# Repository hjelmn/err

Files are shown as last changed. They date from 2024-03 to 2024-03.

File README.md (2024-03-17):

This project contains all the files from my recreation of the Err LED sign. Included
in this repository are the current Kicad files.

The board is roughly based on the data available at:

https://hackaday.io/project/183827-reverse-engineering-the-mooninite-led-panels/details

with minor modifications (there could be errors-- if you find some please post a
PR with the fix):

 - Added a tactile switch to control the mode of the panel. The modes are off,
   light triggered, and various dimmed states but this can be changed by
   modifying the PIC firmware.
 - Added a barrel power input to support an external power supply. Added a
   circuit to disable the batter if an external power supply is connected. This
   circuit uses a P-channel MOSFET which closes the Batt+ when a voltage is
   detected on Vcc.
 - Added a battery pack connector and pads to solder on a battery.
 - Increased the LED driver voltage from 12v to 24v using boost regulator.
 - Changed the 5v regulator to a D2Pak style from the TO-220.
 - Added a 24 channel dimmable LED driver and rewired LEDs in chains of 6-8.
 - Changed to PIC16 to get I2C support but that is not needed with the LED
   controller chosen. It uses PWR so the originsl PIC12 is likely sufficient.

TODO:

 - Code for the microcontroller. Waiting on getting the parts before the code is
   finished.

The current version of the board costs roughly $85 to produce with LEDs from
China and parts sourced from the US.

To use this project download kicad and open the project.

The license for all of these files is GPLv3.

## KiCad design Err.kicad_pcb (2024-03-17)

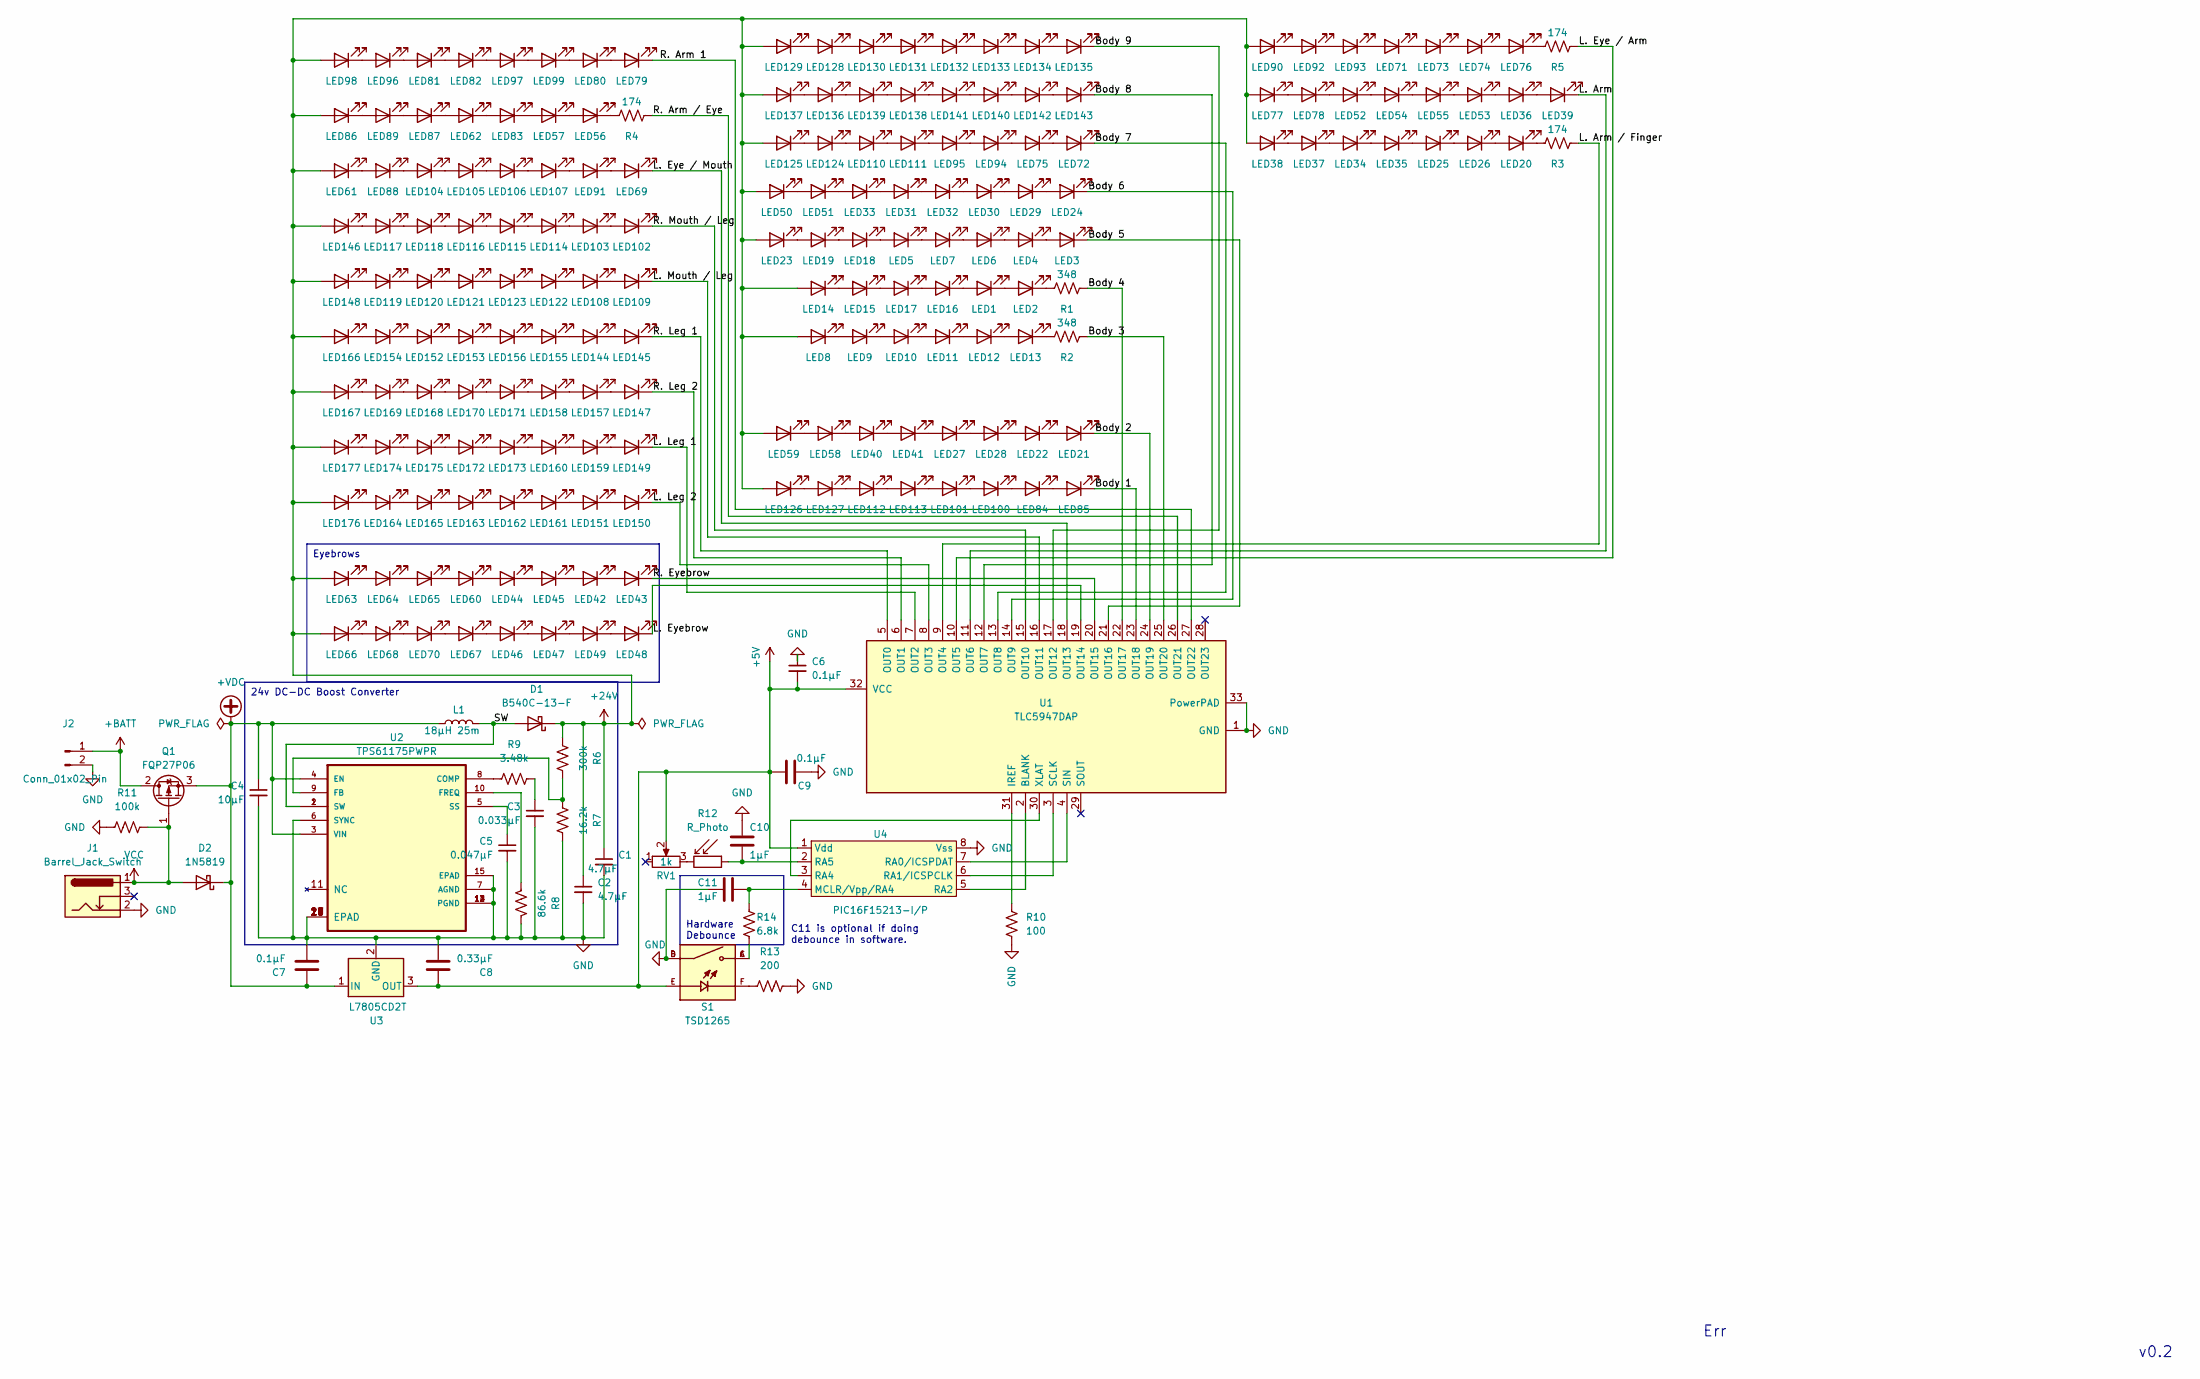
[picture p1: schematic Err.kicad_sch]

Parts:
C1, C2: 4.7µF; C_1206_3216Metric_Pad1.33x1.80mm_HandSolder; Part GRM31CR71H475KA12L
C3: 0.033µF; C_0805_2012Metric_Pad1.18x1.45mm_HandSolder; Part CGA4J2C0G1H333J125AA
C4: 10µF; C_1206_3216Metric_Pad1.33x1.80mm_HandSolder; Part GRM31CR71E106KA12L
C5: 0.047µF; C_0805_2012Metric_Pad1.18x1.45mm_HandSolder; Part C0805C473J3GACTU
C6: 0.1µF; C_0805_2012Metric_Pad1.18x1.45mm_HandSolder; Part GRM31CR71H475KA12L
C7, C9: 0.1µF; C_Disc_D3.0mm_W2.0mm_P2.50mm; Part C320C104K5R5TA
C8: 0.33µF; C_Disc_D5.1mm_W3.2mm_P5.00mm; Part SR215E334MAATR1
C10, C11: 1µF; C_Disc_D5.1mm_W3.2mm_P5.00mm; Part C330C105K5R5TA7301
D1: B540C-13-F; D_SMC-RM10_Universal_Handsoldering; Part B540C-13-F
D2: 1N5819; D_DO-41_SOD81_P10.16mm_Horizontal; Part 1N5819
J1: Barrel_Jack_Switch; BarrelJack_Wuerth_6941xx301002; Part SparkFun PRT-00119
J2: Conn_01x02_Pin; JST_EH_B2B-EH-A_1x02_P2.50mm_Vertical; Part B2B-XH-A
L1: 18µH 25m; IND_SRR1208-120ML; Part SRR1208-180ML
LED1, LED2, LED3, LED4, LED5, LED6, LED7, LED8, LED9, LED10, LED11, LED12, LED13, LED14, LED15, LED16, LED17, LED18, LED19, LED21, LED22, LED23, LED24, LED27, LED28, LED29, LED30, LED31, LED32, LED33, LED40, LED41, LED50, LED51, LED58, LED59, LED72, LED75, LED84, LED85, LED94, LED95, LED100, LED101, LED110, LED111, LED112, LED113, LED124, LED125, LED126, LED127, LED128, LED129, LED130, LED131, LED132, LED133, LED134, LED135, LED136, LED137, LED138, LED139, LED140, LED141, LED142, LED143: LED; LED_D10.0mm; Part 10mm Pink LED
LED20, LED25, LED26, LED34, LED35, LED36, LED37, LED38, LED39, LED42, LED43, LED44, LED45, LED46, LED47, LED48, LED49, LED52, LED53, LED54, LED55, LED56, LED57, LED60, LED61, LED62, LED63, LED64, LED65, LED66, LED67, LED68, LED69, LED70, LED71, LED73, LED74, LED76, LED77, LED78, LED79, LED80, LED81, LED82, LED83, LED86, LED87, LED88, LED89, LED90, LED91, LED92, LED93, LED96, LED97, LED98, LED99, LED102, LED103, LED104, LED105, LED106, LED107, LED108, LED109, LED114, LED115, LED116, LED117, LED118, LED119, LED120, LED121, LED122, LED123, LED144, LED145, LED146, LED147, LED148, LED149, LED150, LED151, LED152, LED153, LED154, LED155, LED156, LED157, LED158, LED159, LED160, LED161, LED162, LED163, LED164, LED165, LED166, LED167, LED168, LED169, LED170, LED171, LED172, LED173, LED174, LED175, LED176, LED177: LED; LED_D10.0mm; Part 10mm Blue LED
Q1: FQP27P06; TO-220-3_Horizontal_TabDown; Part FQP27P06
R1, R2: 348; R_Axial_DIN0207_L6.3mm_D2.5mm_P10.16mm_Horizontal; Part MFR-25FBF52-348R
R3, R4, R5: 174; R_Axial_DIN0207_L6.3mm_D2.5mm_P10.16mm_Horizontal; Part MFR-25FRF52-174R
R6: 300k; R_0603_1608Metric_Pad0.98x0.95mm_HandSolder; Part RC0603FR-07300KL
R7: 16.2k; R_0402_1005Metric_Pad0.72x0.64mm_HandSolder; Part CRCW040216K2FKED
R8: 86.6k; R_0201_0603Metric_Pad0.64x0.40mm_HandSolder; Part RC0201FR-0786K6L
R9: 3.48k; R_0402_1005Metric_Pad0.72x0.64mm_HandSolder; Part CRCW04023K48FKED
R10: 100; R_0805_2012Metric_Pad1.20x1.40mm_HandSolder; Part ERJ-P06F1000V
R11: 100k; R_Axial_DIN0207_L6.3mm_D2.5mm_P10.16mm_Horizontal; Part MFR-25FRF52-100K
R12: R_Photo; R_LDR_D6.4mm_P3.4mm_Vertical; Part SparkFun SEN-09088
R13: 200; R_Axial_DIN0207_L6.3mm_D2.5mm_P10.16mm_Horizontal; Part MFR-25FRF52-200R
R14: 6.8k; R_Axial_DIN0207_L6.3mm_D2.5mm_P10.16mm_Horizontal; Part MFR-25FRF52-200R
RV1: 1k; Potentiometer_Bourns_3299W_Vertical; Part 3299W-1-103LF
S1: TSD1265; SW_TSD1265; PARTREV N/A
U1: TLC5947DAP; HTSSOP-32-1EP_6.1x11mm_P0.65mm_EP5.2x11mm_Mask4.11x4.36mm_T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; Part TLC5947DAP
U2: TPS61175PWPR; IC_TPS27S100BPWPR; Part TPS61175PWPR
U3: L7805CD2T; TO-263-2; Part L7805CD2T
U4: PIC16F15213-I/P; DIP-8_W7.62mm; Part PIC16F15213-I/P

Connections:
+5V: C6.2, C8.1, C9.2, RV1.2, S1.E, U1.32 (VCC), U3.3 (OUT), U4.1 (Vdd)
+24V: C1.1, C2.1, D1.1 (K), LED8.2 (A), LED14.2 (A), LED23.2 (A), LED38.2 (A), LED50.2 (A), LED59.2 (A), LED61.2 (A), LED63.2 (A), LED66.2 (A), LED77.2 (A), LED86.2 (A), LED90.2 (A), LED98.2 (A), LED125.2 (A), LED126.2 (A), LED129.2 (A), LED137.2 (A), LED146.2 (A), LED148.2 (A), LED166.2 (A), LED167.2 (A), LED176.2 (A), LED177.2 (A), R6.2
+BATT: J2.1, Q1.2 (D)
+VDC: C4.1, C7.2, D2.1 (K), L1.1, Q1.3 (S), U2.3 (VIN), U2.4 (EN), U3.1 (IN)
/Body 1: LED85.1 (K), U1.23 (OUT18)
/Body 2: LED21.1 (K), U1.24 (OUT19)
/Body 3: R2.2, U1.25 (OUT20)
/Body 4: R1.2, U1.22 (OUT17)
/Body 5: LED3.1 (K), U1.21 (OUT16)
/Body 6: LED24.1 (K), U1.14 (OUT9)
/Body 7: LED72.1 (K), U1.13 (OUT8)
/Body 8: LED143.1 (K), U1.12 (OUT7)
/Body 9: LED135.1 (K), U1.17 (OUT12)
/L. Arm: LED39.1 (K), U1.11 (OUT6)
/L. Arm / Finger: R3.2, U1.9 (OUT4)
/L. Eye / Arm: R5.1, U1.10 (OUT5)
/L. Eye / Mouth: LED69.1 (K), U1.18 (OUT13)
/L. Eyebrow: LED48.1 (K), U1.19 (OUT14)
/L. Leg 1: LED149.1 (K), U1.7 (OUT2)
/L. Leg 2: LED150.1 (K), U1.8 (OUT3)
/L. Mouth / Leg: LED109.1 (K), U1.16 (OUT11)
/R. Arm 1: LED79.1 (K), U1.27 (OUT22)
/R. Arm / Eye: R4.1, U1.26 (OUT21)
/R. Eyebrow: LED43.1 (K), U1.20 (OUT15)
/R. Leg 1: LED145.1 (K), U1.5 (OUT0)
/R. Leg 2: LED147.1 (K), U1.6 (OUT1)
/R. Mouth / Leg: LED102.1 (K), U1.15 (OUT10)
/SW: D1.2 (A), L1.2, U2.1 (SW), U2.2 (SW)
GND: C1.2, C2.2, C3.2, C4.2, C5.2, C6.1, C7.1, C8.2, C9.1, C10.1, C11.2, J1.2, J2.2, R7.1, R8.2, R10.1, R11.2, R13.1, S1.B, S1.D, U1.1 (GND), U1.33 (PowerPAD), U2.6 (SYNC), U2.7 (AGND), U2.12 (PGND), U2.13 (PGND), U2.14 (PGND), U2.15 (EPAD), U2.16 (EPAD), U2.17 (EPAD), U2.18 (EPAD), U2.19 (EPAD), U2.20 (EPAD), U2.21 (EPAD), U3.2 (GND), U4.8 (Vss)
unnamed: C3.1, R9.1
unnamed: LED1.2 (A), LED16.1 (K)
unnamed: LED1.1 (K), LED2.2 (A)
unnamed: LED2.1 (K), R1.1
unnamed: LED3.2 (A), LED4.1 (K)
unnamed: LED4.2 (A), LED6.1 (K)
unnamed: LED5.1 (K), LED7.2 (A)
unnamed: LED6.2 (A), LED7.1 (K)
unnamed: LED8.1 (K), LED9.2 (A)
unnamed: LED9.1 (K), LED10.2 (A)
unnamed: LED10.1 (K), LED11.2 (A)
unnamed: LED11.1 (K), LED12.2 (A)
unnamed: LED12.1 (K), LED13.2 (A)
unnamed: LED13.1 (K), R2.1
unnamed: LED14.1 (K), LED15.2 (A)
unnamed: LED15.1 (K), LED17.2 (A)
unnamed: LED16.2 (A), LED17.1 (K)
unnamed: LED18.2 (A), LED19.1 (K)
unnamed: LED5.2 (A), LED18.1 (K)
unnamed: LED19.2 (A), LED23.1 (K)
unnamed: LED20.2 (A), LED26.1 (K)
unnamed: LED20.1 (K), R3.1
unnamed: LED21.2 (A), LED22.1 (K)
unnamed: LED22.2 (A), LED28.1 (K)
unnamed: LED24.2 (A), LED29.1 (K)
unnamed: LED25.2 (A), LED35.1 (K)
unnamed: LED25.1 (K), LED26.2 (A)
unnamed: LED27.2 (A), LED41.1 (K)
unnamed: LED27.1 (K), LED28.2 (A)
unnamed: LED29.2 (A), LED30.1 (K)
unnamed: LED30.2 (A), LED32.1 (K)
unnamed: LED31.2 (A), LED33.1 (K)
unnamed: LED31.1 (K), LED32.2 (A)
unnamed: LED33.2 (A), LED51.1 (K)
unnamed: LED34.2 (A), LED37.1 (K)
unnamed: LED34.1 (K), LED35.2 (A)
unnamed: LED36.2 (A), LED53.1 (K)
unnamed: LED36.1 (K), LED39.2 (A)
unnamed: LED37.2 (A), LED38.1 (K)
unnamed: LED40.2 (A), LED58.1 (K)
unnamed: LED40.1 (K), LED41.2 (A)
unnamed: LED42.2 (A), LED45.1 (K)
unnamed: LED42.1 (K), LED43.2 (A)
unnamed: LED44.2 (A), LED60.1 (K)
unnamed: LED44.1 (K), LED45.2 (A)
unnamed: LED46.2 (A), LED67.1 (K)
unnamed: LED46.1 (K), LED47.2 (A)
unnamed: LED47.1 (K), LED49.2 (A)
unnamed: LED48.2 (A), LED49.1 (K)
unnamed: LED50.1 (K), LED51.2 (A)
unnamed: LED52.2 (A), LED78.1 (K)
unnamed: LED52.1 (K), LED54.2 (A)
unnamed: LED53.2 (A), LED55.1 (K)
unnamed: LED54.1 (K), LED55.2 (A)
unnamed: LED56.2 (A), LED57.1 (K)
unnamed: LED56.1 (K), R4.2
unnamed: LED57.2 (A), LED83.1 (K)
unnamed: LED58.2 (A), LED59.1 (K)
unnamed: LED60.2 (A), LED65.1 (K)
unnamed: LED61.1 (K), LED88.2 (A)
unnamed: LED62.2 (A), LED87.1 (K)
unnamed: LED62.1 (K), LED83.2 (A)
unnamed: LED63.1 (K), LED64.2 (A)
unnamed: LED64.1 (K), LED65.2 (A)
unnamed: LED66.1 (K), LED68.2 (A)
unnamed: LED67.2 (A), LED70.1 (K)
unnamed: LED68.1 (K), LED70.2 (A)
unnamed: LED69.2 (A), LED91.1 (K)
unnamed: LED71.2 (A), LED93.1 (K)
unnamed: LED71.1 (K), LED73.2 (A)
unnamed: LED72.2 (A), LED75.1 (K)
unnamed: LED73.1 (K), LED74.2 (A)
unnamed: LED74.1 (K), LED76.2 (A)
unnamed: LED75.2 (A), LED94.1 (K)
unnamed: LED76.1 (K), R5.2
unnamed: LED77.1 (K), LED78.2 (A)
unnamed: LED79.2 (A), LED80.1 (K)
unnamed: LED80.2 (A), LED99.1 (K)
unnamed: LED81.2 (A), LED96.1 (K)
unnamed: LED81.1 (K), LED82.2 (A)
unnamed: LED82.1 (K), LED97.2 (A)
unnamed: LED84.1 (K), LED85.2 (A)
unnamed: LED86.1 (K), LED89.2 (A)
unnamed: LED87.2 (A), LED89.1 (K)
unnamed: LED90.1 (K), LED92.2 (A)
unnamed: LED92.1 (K), LED93.2 (A)
unnamed: LED94.2 (A), LED95.1 (K)
unnamed: LED96.2 (A), LED98.1 (K)
unnamed: LED97.1 (K), LED99.2 (A)
unnamed: LED100.2 (A), LED101.1 (K)
unnamed: LED84.2 (A), LED100.1 (K)
unnamed: LED101.2 (A), LED113.1 (K)
unnamed: LED102.2 (A), LED103.1 (K)
unnamed: LED103.2 (A), LED114.1 (K)
unnamed: LED88.1 (K), LED104.2 (A)
unnamed: LED104.1 (K), LED105.2 (A)
unnamed: LED105.1 (K), LED106.2 (A)
unnamed: LED106.1 (K), LED107.2 (A)
unnamed: LED91.2 (A), LED107.1 (K)
unnamed: LED108.2 (A), LED122.1 (K)
unnamed: LED108.1 (K), LED109.2 (A)
unnamed: LED110.2 (A), LED124.1 (K)
unnamed: LED110.1 (K), LED111.2 (A)
unnamed: LED95.2 (A), LED111.1 (K)
unnamed: LED112.2 (A), LED127.1 (K)
unnamed: LED112.1 (K), LED113.2 (A)
unnamed: LED114.2 (A), LED115.1 (K)
unnamed: LED115.2 (A), LED116.1 (K)
unnamed: LED116.2 (A), LED118.1 (K)
unnamed: LED117.2 (A), LED146.1 (K)
unnamed: LED117.1 (K), LED118.2 (A)
unnamed: LED119.2 (A), LED148.1 (K)
unnamed: LED119.1 (K), LED120.2 (A)
unnamed: LED120.1 (K), LED121.2 (A)
unnamed: LED121.1 (K), LED123.2 (A)
unnamed: LED122.2 (A), LED123.1 (K)
unnamed: LED124.2 (A), LED125.1 (K)
unnamed: LED126.1 (K), LED127.2 (A)
unnamed: LED128.2 (A), LED129.1 (K)
unnamed: LED128.1 (K), LED130.2 (A)
unnamed: LED130.1 (K), LED131.2 (A)
unnamed: LED131.1 (K), LED132.2 (A)
unnamed: LED132.1 (K), LED133.2 (A)
unnamed: LED133.1 (K), LED134.2 (A)
unnamed: LED134.1 (K), LED135.2 (A)
unnamed: LED136.2 (A), LED137.1 (K)
unnamed: LED136.1 (K), LED139.2 (A)
unnamed: LED138.2 (A), LED139.1 (K)
unnamed: LED138.1 (K), LED141.2 (A)
unnamed: LED140.2 (A), LED141.1 (K)
unnamed: LED140.1 (K), LED142.2 (A)
unnamed: LED142.1 (K), LED143.2 (A)
unnamed: LED144.2 (A), LED155.1 (K)
unnamed: LED144.1 (K), LED145.2 (A)
unnamed: LED147.2 (A), LED157.1 (K)
unnamed: LED149.2 (A), LED159.1 (K)
unnamed: LED150.2 (A), LED151.1 (K)
unnamed: LED151.2 (A), LED161.1 (K)
unnamed: LED152.2 (A), LED154.1 (K)
unnamed: LED152.1 (K), LED153.2 (A)
unnamed: LED153.1 (K), LED156.2 (A)
unnamed: LED154.2 (A), LED166.1 (K)
unnamed: LED155.2 (A), LED156.1 (K)
unnamed: LED157.2 (A), LED158.1 (K)
unnamed: LED158.2 (A), LED171.1 (K)
unnamed: LED159.2 (A), LED160.1 (K)
unnamed: LED160.2 (A), LED173.1 (K)
unnamed: LED161.2 (A), LED162.1 (K)
unnamed: LED162.2 (A), LED163.1 (K)
unnamed: LED163.2 (A), LED165.1 (K)
unnamed: LED164.2 (A), LED176.1 (K)
unnamed: LED164.1 (K), LED165.2 (A)
unnamed: LED167.1 (K), LED169.2 (A)
unnamed: LED168.2 (A), LED169.1 (K)
unnamed: LED168.1 (K), LED170.2 (A)
unnamed: LED170.1 (K), LED171.2 (A)
unnamed: LED172.2 (A), LED175.1 (K)
unnamed: LED172.1 (K), LED173.2 (A)
unnamed: LED174.2 (A), LED177.1 (K)
unnamed: LED174.1 (K), LED175.2 (A)
unnamed: R12.2, RV1.3
unnamed: R13.2, S1.F
unnamed: R14.1, S1.A, S1.C
unnamed: U1.2 (BLANK), U4.5 (RA2)
unnamed: R10.2, U1.31 (IREF)
unnamed: U1.3 (SCLK), U4.6 (RA1/ICSPCLK)
unnamed: U1.4 (SIN), U4.7 (RA0/ICSPDAT)
unnamed: U1.30 (XLAT), U4.3 (RA4)
unnamed: R9.2, U2.8 (COMP)
unnamed: R6.1, R7.2, U2.9 (FB)
unnamed: R8.1, U2.10 (FREQ)
unnamed: C5.1, U2.5 (SS)
unnamed: C11.1, R14.2, U4.4 (MCLR/Vpp/RA4)
unnamed: C10.2, R12.1, U4.2 (RA5)
VCC: D2.2 (A), J1.1, Q1.1 (G), R11.1

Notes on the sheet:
Hardware Debounce
Eyebrows
24v DC-DC Boost Converter
C11 is optional if doing debounce in software.
v0.2
Err

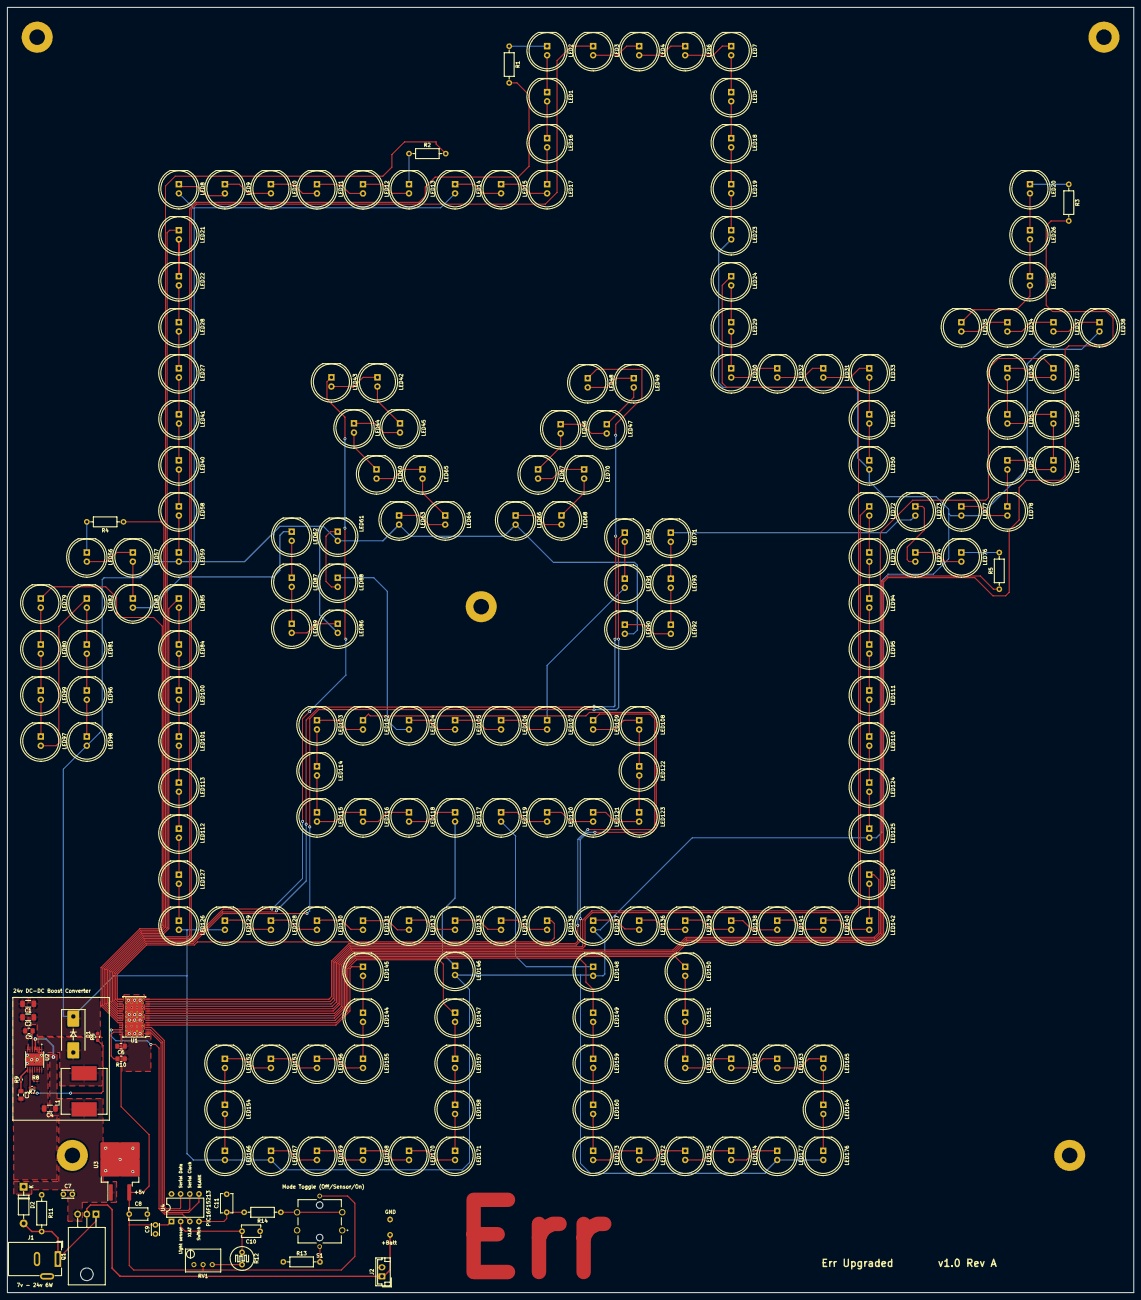
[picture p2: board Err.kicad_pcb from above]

Board: 2 copper layers, 312.0 x 356.0 mm, 214 parts (0 on the bottom side), 204 nets.
